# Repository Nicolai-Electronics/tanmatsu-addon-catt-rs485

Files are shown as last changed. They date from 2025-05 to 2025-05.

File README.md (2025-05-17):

# Tanmatsu add-on: CATT RS-485 & RS-422 adapter

This repository contains the hardware design files for the CATT RS-485 & RS-422 adapter.

## Documentation

Need the schematic? [It's in this repository as a PDF file](schematic.pdf).

## License

This hardware design may be used under the terms of the [CERN-OHL-P](LICENSE) license.

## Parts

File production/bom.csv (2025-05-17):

Designator | Footprint | Quantity | Value | LCSC Part #
C1, C2, C3 | 0402 | 3 | 100n | C307331
C4 | 0805 | 1 | 22u | C602037
D1, D2, D3 | 0603 | 3 | LED | C7496820
J1 | PinHeader_2x07_P2.54mm_Horizontal | 1 | CATT | C492435
J2 | CONN-TH_WJ15EDGRC-3.81-6P | 1 | Output | C7246
R1, R2, R3, R6, R7, R8 | 0402 | 6 | 100k | C25741
R4, R5, R9 | 0402 | 3 | 1k | C11702
U1, U2 | SOIC-8_3.9x4.9mm_P1.27mm | 2 | SN65HVD75DR | C57928
U3 | SOP-8_3.9x4.9mm_P1.27mm | 1 | 24C02BN | C18723542

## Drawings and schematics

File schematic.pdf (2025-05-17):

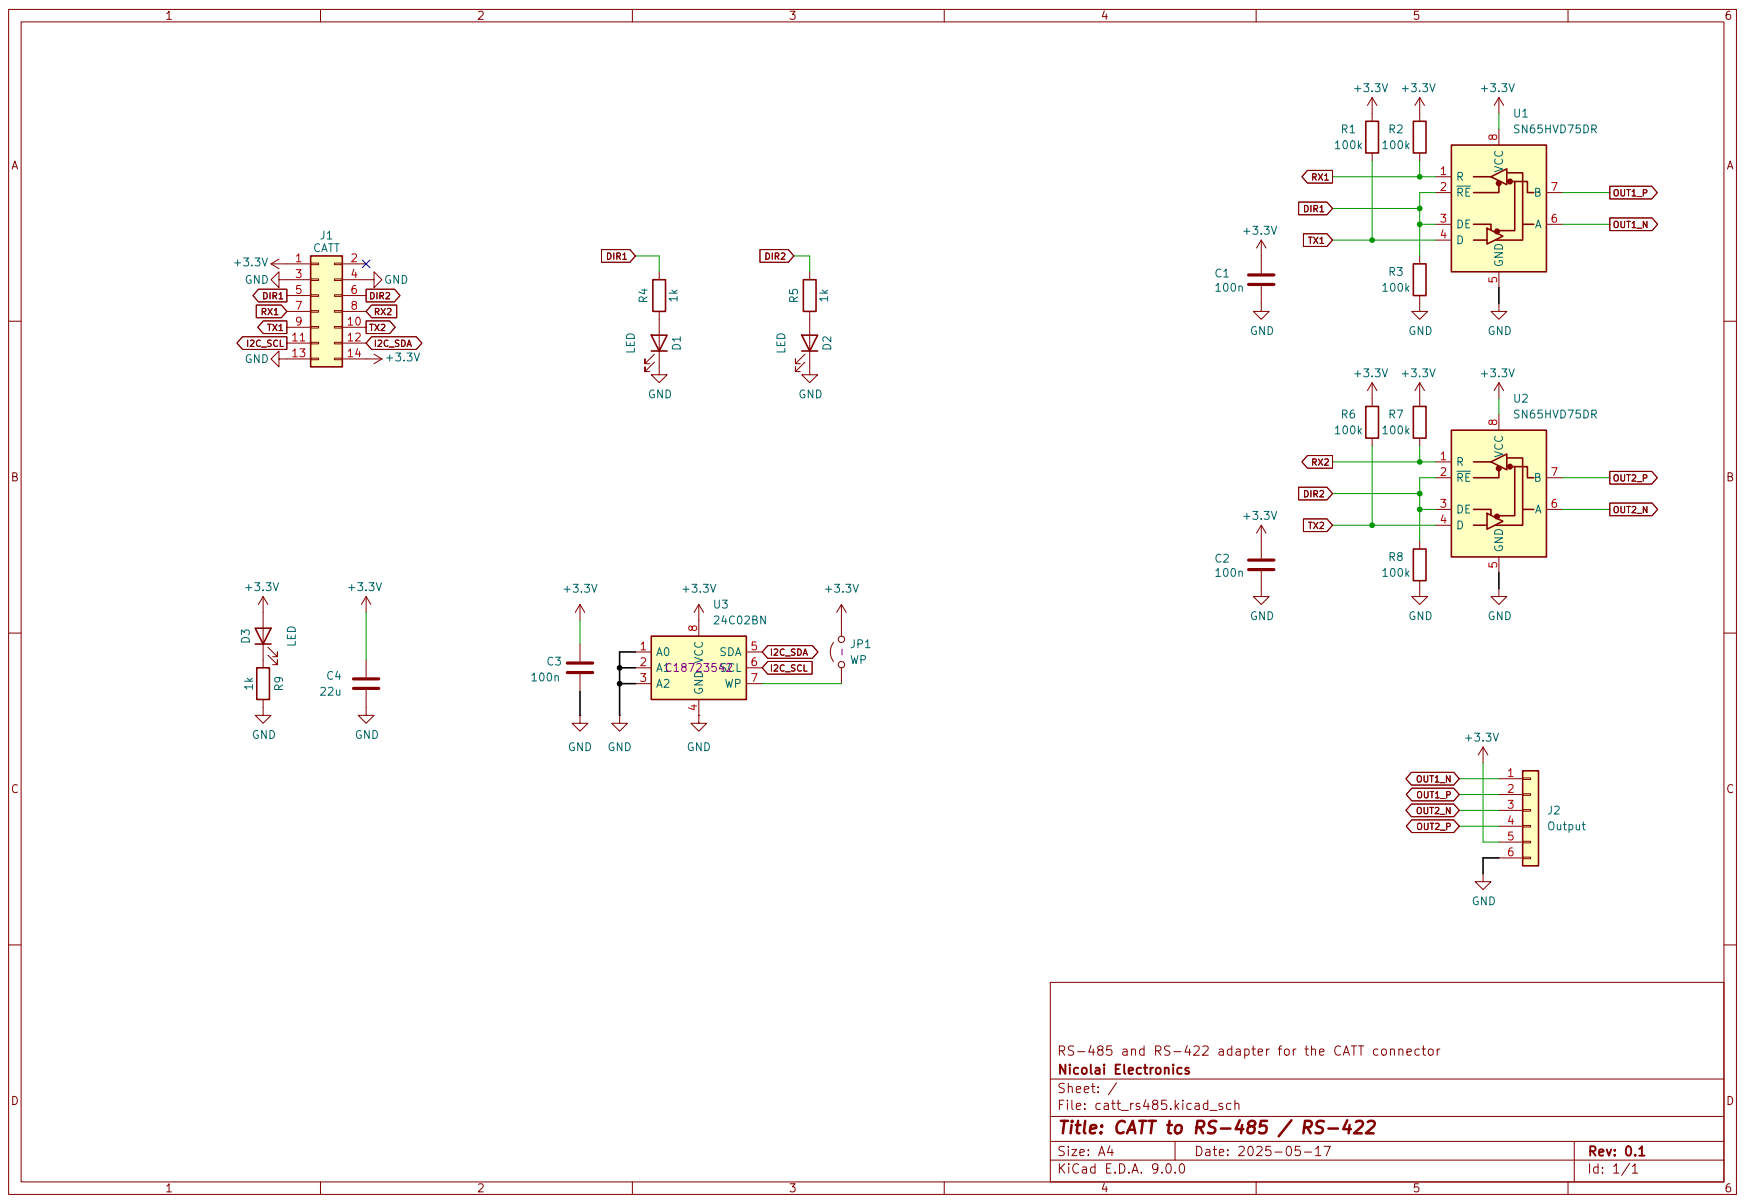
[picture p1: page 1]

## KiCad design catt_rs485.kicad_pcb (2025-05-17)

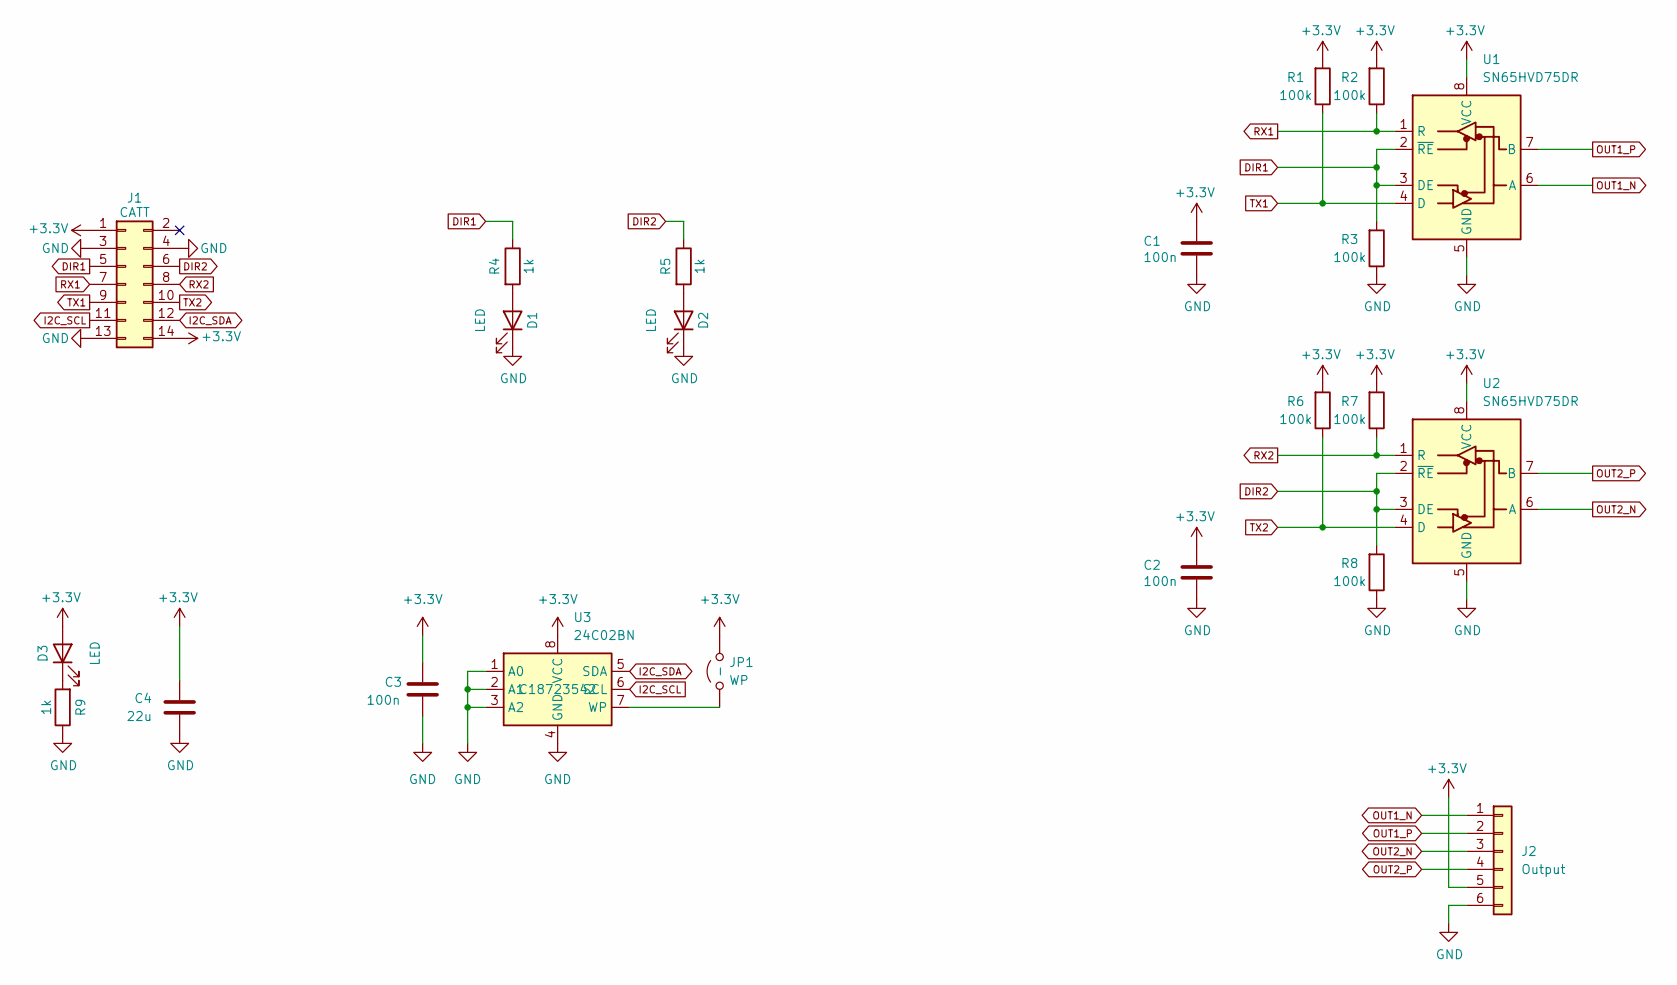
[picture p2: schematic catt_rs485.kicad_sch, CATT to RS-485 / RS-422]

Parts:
C1, C2, C3: 100n; C_0402_1005Metric; LCSC C307331
C4: 22u; C_0805_2012Metric; LCSC C602037
D1, D2, D3: LED; LED_0603_1608Metric; LCSC C7496820
J1: CATT; PinHeader_2x07_P2.54mm_Horizontal; LCSC C492435
J2: Output; CONN-TH_WJ15EDGRC-3.81-6P; LCSC C7246
JP1: WP; SolderJumper-2_P1.3mm_Open_TrianglePad1.0x1.5mm
R1, R2, R3, R6, R7, R8: 100k; R_0402_1005Metric; LCSC C25741
R4, R5, R9: 1k; R_0402_1005Metric; LCSC C11702
U1, U2: SN65HVD75DR; SOIC-8_3.9x4.9mm_P1.27mm; LCSC C57928
U3: 24C02BN; SOP-8_3.9x4.9mm_P1.27mm; LCSC C18723542

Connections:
+3.3V: C1.1, C2.1, C3.1, C4.1, D3.2 (A), J1.1, J1.14, J2.5, JP1.2 (B), R1.2, R2.2, R6.2, R7.2, U1.8 (VCC), U2.8 (VCC), U3.8 (VCC)
DIR1: J1.5, R3.2, R4.1, U1.2 (~RE), U1.3 (DE)
DIR2: J1.6, R5.1, R8.2, U2.2 (~RE), U2.3 (DE)
GND: C1.2, C2.2, C3.2, C4.2, D1.1 (K), D2.1 (K), J1.3, J1.4, J1.13, J2.6, R3.1, R8.1, R9.1, U1.5 (GND), U2.5 (GND), U3.1 (A0), U3.2 (A1), U3.3 (A2), U3.4 (GND)
I2C_SCL: J1.11, U3.6 (SCL)
I2C_SDA: J1.12, U3.5 (SDA)
unnamed: D1.2 (A), R4.2
unnamed: D2.2 (A), R5.2
unnamed: D3.1 (K), R9.2
unnamed: JP1.1 (A), U3.7 (WP)
OUT1_N: J2.1, U1.6 (A)
OUT1_P: J2.2, U1.7 (B)
OUT2_N: J2.3, U2.6 (A)
OUT2_P: J2.4, U2.7 (B)
RX1: J1.7, R2.1, U1.1 (R)
RX2: J1.8, R7.1, U2.1 (R)
TX1: J1.9, R1.1, U1.4 (D)
TX2: J1.10, R6.1, U2.4 (D)

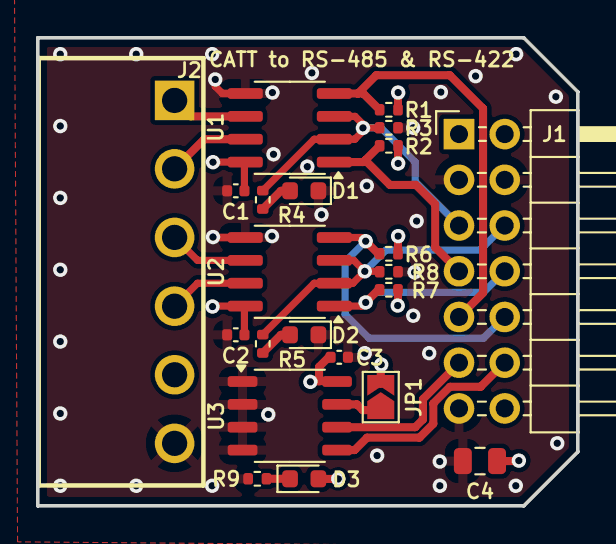
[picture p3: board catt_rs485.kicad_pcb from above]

Board: 4 copper layers, 30.0 x 26.0 mm, 22 parts (0 on the bottom side), 18 nets.

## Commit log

2025-05-17 Renumber components
    [bom.csv, catt_rs485.kicad_pcb, catt_rs485.kicad_sch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]
2025-05-17 Add missing LCSC number of output connector
    [bom.csv, catt_rs485.kicad_pcb, catt_rs485.kicad_sch]
